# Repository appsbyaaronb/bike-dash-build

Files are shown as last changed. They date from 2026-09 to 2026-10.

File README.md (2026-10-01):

# bike-dash-build

Hardware + software build notes for the **permanent** electric-motorcycle dash.
This repo is the "how to build it" companion to two existing repos:

| Repo | What it holds |
|---|---|
| [appsbyaaronb/bike-dash](https://github.com/appsbyaaronb/bike-dash) (private) | The dash firmware (ESPHome/LVGL): GPS speed, BMS status, media strip, SD ride log |
| [appsbyaaronb/ant-bms-epaper-gauge](https://github.com/appsbyaaronb/ant-bms-epaper-gauge) (public) | The original e-paper SOC gauge; the ANT-BMS BLE logic came from here |

## The decision (2026-09-18)

Cost is not a factor. Performance and start-up time are.

| Question | Answer |
|---|---|
| Compute | **ESP32-P4 + ESP32-C6** under ESPHome. About 3 s from key-on to a usable screen. Everything already written for bike-dash carries over. |
| Why not a Pi / Linux board | 15-30 s boot. Rejected. |
| Why not STM32H7 | Under 1 s boot but no BLE and nothing carries over. Rejected. |
| Why not the Waveshare ESP32-P4-7B we started on | Its panel is **350 nits, 0-60 C**. Every ESP32-P4 all-in-one board on the market (Waveshare, Guition, Elecrow) is an indoor panel. A bike dash in direct sun needs about 1000 nits. |
| Screen | **Riverdi RVT70HSMNWC00-B**: 7" 1024x600 IPS, **850 cd/m2**, optically bonded PCAP touch, anti-glare, **-20 to 70 C**, glove and wet-screen touch. Controller EK79007 (same family as Espressif's own dev panel), runs 2-lane. |
| Board | **Waveshare ESP32-P4-NANO** (P4 + onboard C6, 32 MB PSRAM, 16 MB flash, microSD, 15-pin 1.0 mm 2-lane DSI). |
| Glue | Two FPC breakouts for the bench, an eletechsup LD24AJTA constant-current driver (pot-set) for the 9.6 V / 270 mA backlight, a Pololu 5 V buck off the bike's 12 V. A small carrier PCB replaces the breakouts for the on-bike install. |

## Bench wiring at a glance

Bench wiring diagram

Full pin-by-pin steps, checks and troubleshooting: [docs/wiring.md](docs/wiring.md).

## Where things are

| File | Contents |
|---|---|
| [docs/bom.md](docs/bom.md) | Every part, price, link, and order status |
| [docs/wiring.md](docs/wiring.md) | **Pin-for-pin wiring guide.** Start here when the parts arrive. |
| [docs/hardware.md](docs/hardware.md) | Pinouts, panel electrical limits, timings, gotchas (the reference behind the wiring guide) |
| [docs/software.md](docs/software.md) | ESPHome bring-up plan, versions, stages |
| [esphome/bike-dash-p4nano.yaml](esphome/bike-dash-p4nano.yaml) | Starting config: P4-NANO + Riverdi panel as a `mipi_dsi` CUSTOM model |
| [esphome/bike-dash-live.yaml](esphome/bike-dash-live.yaml) | **Current working firmware** (no panel yet): BMS over BLE, iPhone media remote, dash page on :8080, fixed IP |
| [esphome/components/](esphome/components/) | Custom components: `ams` (iPhone Apple Media Service remote), `dash_page` (serves dash pages, media/restart commands), `log_page` (device log with a fixed-size buffer) |
| [esphome/dash.html](esphome/dash.html) | 1024x600 dash page, built into the firmware (:8080) |
| [esphome/phone.html](esphome/phone.html) | Phone dash, 19.5:9, scales to the window (:8082) |
| [docs/build-log.md](docs/build-log.md) | Dated log of what was done and what was learned |
| [enclosure/](enclosure/README.md) | OpenSCAD model, STLs and previews of the printed housing (bezel, retainer, shell, GPS cap) |

## Enclosure at a glance

Enclosure mockup

Four printed parts, PETG/ASA, M3 inserts. Details, hardware list and the VERIFY table: [enclosure/README.md](enclosure/README.md).

## Status

- 2026-09-18: research done, all core parts ordered (Amazon plus the Riverdi panel from DigiKey). Nothing built yet.
- 2026-09-18: enclosure mockup modelled in OpenSCAD, STLs exported. Several dimensions still need calipers on the real parts (see enclosure/README.md).
- 2026-09-28: board flashed. BMS live over the C6, iPhone media control working, dash page at `http://192.168.7.18:8080/`. Panel and GPS not connected yet.
- 2026-10-01: the P4-NANO display socket turned out to be 15-pin 1.0 mm, not 22-pin; the right breakout and cable are ordered (due Oct 3). Whole plan re-checked against Riverdi's datasheet for the exact panel; corrections are in docs/build-log.md.
- Board pages: dash `:8080`, log `:8081`, phone dash `:8082`, ESPHome web/API `:80`. Fixed IP 192.168.7.18 on IoT2.4; the iPhone hotspot is the backup network.

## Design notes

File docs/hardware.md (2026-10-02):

# Hardware reference

This is the reference behind [wiring.md](wiring.md). Read wiring.md to build it; come here when something does not work.

## Riverdi RVT70HSMNWC00-B panel

Riverdi's files for this exact part, in the folder https://download.riverdi.com/RVT70HSMNWC00-B/ : datasheet `DS_RVT70HSMNWC00-B V1.1A_Rev.1.0.pdf` (2026-07-20), drawing `DR_RVT70HSMNWC00-B V1.1A_Rev.1.0.pdf`, backlight app note `AN_RVT70HSMNWC00-B_Rev1.1.pdf`. The old Rev 1.4 link is dead. Do not commit the PDFs, link them.

These documents are for module revision **V1.1A**. The panel bought from DigiKey is listed as **V1.0A**. The pinout matches the 2024 app note, which covers both, so the electrical side is safe; treat the mechanical numbers as approximate until measured. Everything below was re-checked against these files on 2026-10-01.

| Item | Value |
|---|---|
| Controller | EK79007AD3 + EK73217BCGA (datasheet drawing). Espressif ships `esp_lcd_ek79007`; ESPHome `mipi_dsi` drives it as `model: CUSTOM` |
| Resolution | 1024 x 600, IPS, normally black, anti-glare |
| Brightness | 1000 cd/m2 bare; 850 cd/m2 with the optically bonded touch |
| Operating temp | -20 to 70 C (storage -30 to 80) |
| Logic supply | VDD 3.3 V (3.0-3.6), 110 mA typ, 120 max. Touch adds about 98 mA on its own 3.3 V pin. The NANO's 3.3 V regulator is a 3 A buck, so this is fine. |
| Backlight | 27 white LEDs, 9 strings of 3. **Vf 9.0 V typ (8.4-10.2), If 270 mA**, about 2.4 W. Absolute maximum is 30 mA per string, which is 270 mA total: **270 mA is the ceiling, not a midpoint.** No driver on the panel. |
| Touch | ILITEK ILI2132A PCAP, I2C address **0x41** (or USB HID), 10-point, thick-glove and wet operation. Not supported by ESPHome yet. |
| Touch tail | Separate 10-pin FPC off the touch controller board (printed on the tail): 1 GND, 2 VDD5V, 3 D-, 4 D+, 5 GND, 6 VCC, 7 RST, 8 SCL, 9 INT, 10 SDA. Pins 2-4 are a USB HID path, pins 6-10 the I2C path. The controller board also has a small white JST socket (CN1, the same USB signals). Wired over I2C in this build: wiring.md Step 4a. I2C VDD is 3.3 V only. |
| Size | Cover glass 179.96 x 119.00 mm, 1.1 mm thick. TFT body 164.9 x 100 mm. Whole module 7.68 mm thick max. Active area 154.21 x 85.92 mm. |
| Tail | 40-pin 0.5 mm pitch FPC, 0.3 mm thick, contacts on one side |
| Touch tail | 10-pin 0.5 mm pitch FPC, 0.3 mm thick |

### 40-pin FPC pinout (datasheet)

| Pin | Name | Note |
|---|---|---|
| 1 | NC | |
| 2, 3 | VDD | 3.3 V |
| 4 | NC | |
| 5 | RESET | active low; datasheet Note 1 has a recommended RC reset circuit |
| 6 | STBYB | standby, high for normal operation. Driven from GPIO5 (P1 pin 11) |
| 7 | GND | |
| 8, 9 | D0N, D0P | MIPI lane 0 |
| 10 | GND | |
| 11, 12 | D1N, D1P | MIPI lane 1 |
| 13 | GND | |
| 14, 15 | D2N, D2P | lane 2, **leave unconnected** (P4 is 2-lane) |
| 16 | GND | |
| 17, 18 | DCLKN, DCLKP | MIPI clock |
| 19 | GND | |
| 20, 21 | D3N, D3P | lane 3, **leave unconnected** |
| 22 | GND | |
| 23, 24 | NC | |
| 25 | GND | |
| 26-29 | NC | |
| 30 | GND | |
| 31, 32 | LED- | backlight cathode |
| 33 | L/R | horizontal scan direction. **Must be tied**: 3.3 V = left to right (normal) |
| 34 | U/D | vertical scan direction. **Must be tied**: GND = top to bottom (normal) |
| 35-38 | NC | |
| 39, 40 | LED+ | backlight anode |

### Init sequence (datasheet section 13). This is what goes in the ESPHome `init_sequence`

```
0x01            ; DCS software reset
delay 120 ms
0xB2 0x50       ; lanes: 0x50 = 2-lane, 0x60 = 3, 0x70 = 4   <-- P4 uses 2
0x80 0x4B       ; gamma
0x81 0xFF
0x82 0x1A
0x83 0x88
0x84 0x8F
0x85 0x35
0x86 0xB0
0x11            ; exit sleep
delay 120 ms
0x29            ; display on
delay 20 ms
```

### Timing (datasheet, typical / range)

| Parameter | Typ | Range |
|---|---|---|
| Pixel clock | 51.2 MHz | 44.9-63 MHz |
| H active | 1024 | |
| H total (one line) | 1344 | 1200-1400 |
| HSYNC pulse | no typ given; config uses 10 | 1-140 |
| H back porch | 160 | fixed |
| H front porch | 160 | 16-216 |
| V active | 600 | |
| V total | 635 | 624-750 |
| VSYNC pulse | no typ given; config uses 1 | 1-20 |
| V back porch | 23 | fixed |
| V front porch | 12 | 1-127 |

### Gotchas from the datasheet

- **THS_ZERO**: the panel's MIPI receiver does not meet the MIPI minimum. If the host's THS_ZERO sits at the low end the panel may not initialise correctly and the picture "jumps". Riverdi says to set THS_ZERO to about **213 ns** in the DSI PHY. ESPHome has no setting for it; it would be an ESP-IDF PHY timing change.
- The pulse widths are 10 and 1, not 70 and 10: with a 70-wide pulse the line comes to 1414 clocks, over the 1400 maximum. 10/160/160 and 1/23/12 are what Espressif's `esp_lcd_ek79007` driver and the ESPHome Waveshare 7B preset use for the same controller (`lane_bit_rate: 900Mbps`, `pclk 52MHz`).
- That same Espressif driver sends `0xB2, 0x10` for 2 lanes and different gamma bytes. Riverdi's datasheet says `0x50`. The config uses Riverdi's; `0x10` is the first thing to try if the panel stays black.

## Waveshare ESP32-P4-NANO

Wiki: https://www.waveshare.com/wiki/ESP32-P4-Nano-StartPage . Schematic: https://files.waveshare.com/wiki/ESP32-P4-NANO/ESP32-P4-NANO-schematic.pdf

| Item | Value |
|---|---|
| SoC | ESP32-P4NRW32, 32 MB PSRAM in package, 16 MB QSPI flash |
| Radio | ESP32-C6-MINI-1 over SDIO: reset GPIO54, cmd 19, clk 18, d0-d3 = 14-17, active high (ESPHome device page) |
| I2C | SDA GPIO7, SCL GPIO8 (also on the DSI connector) |
| LCD reset (BSP default) | GPIO27 on the GPIO header |
| LCD backlight PWM (BSP default) | GPIO26 on the GPIO header |
| DSI | 15-pin 1.0 mm FPC (J1, "15PIN--PI4B", Raspberry Pi 4 layout), 2 lanes + clock. Pins: 1 GND, 2 D1-, 3 D1+, 4 GND, 5 CLK-, 6 CLK+, 7 GND, 8 D0-, 9 D0+, 10 GND, 11 SCL, 12 SDA, 13 GND, 14-15 3V3. We only use the six MIPI signals and ground from this connector; reset and backlight go from the header instead. |
| Power | USB-C, or 5 V on the header, or PoE module |

Header **P1** (2x13, 2.54 mm), from the schematic. Every pin this build uses is on P1:

| Pin | Signal | Use | | Pin | Signal | Use |
|---|---|---|---|---|---|---|
| 1 | 3V3 | panel 33 (L/R) | | 2 | 5V | Pololu 5 V in |
| 3 | GPIO7 | I2C SDA (touch) | | 4 | 5V | GPS 5V |
| 5 | GPIO8 | I2C SCL (touch) | | 6 | GND | |
| 7 | GPIO23 | touch RST | | 8 | GPIO37 | |
| 9 | GND | | | 10 | GPIO38 | |
| 11 | GPIO5 | panel STBYB (pin 6) | | 12 | GPIO4 | |
| 13 | GPIO20 | GPS UART TX (P4 → GPS RX) | | 14 | GND | |
| 15 | GPIO21 | GPS UART RX (GPS TX → P4) | | 16 | GPIO22 | touch INT |
| 17 | 3V3 | touch VCC | | 18 | GPIO24 | USB-Serial-JTAG D−, left free |
| 19 | GPIO25 | USB-Serial-JTAG D+, left free | | 20 | GND | |
| 21 | GPIO26 | backlight PWM | | 22 | GPIO27 | panel RESET |
| 23 | GPIO32 | | | 24 | GPIO33 | |
| 25 | GND | | | 26 | GPIO36 | |

Header P2 carries GPIO0-3, 6, 45-48, 53, 54 and the C6 UART; not used here.

Storage is microSD (SDIO 3.0). The only ESPHome preset for this board is `WAVESHARE-P4-NANO-10.1` (their 10.1" DSI panel); copy only the board-level bits.

## Backlight driver: eletechsup LD24AJTA

- Buck constant-current, 6-24 V in, 30-900 mA set by a pot. Ceiling is 0.1 V / RCS. Ordered 2026-09-28 from AliExpress ($1.15).
- Set to **260 mA** on a meter before connecting the panel, never above 270 (wiring.md step 1). Bare pads: VIN, GND, LED+, LED-, PWM, GND.
- Buck topology: Vin must be above the LED string (9.0 V typ, 10.2 max) plus headroom. 12 V is fine. 5 V is not. Headroom not in the listing; check brightness on the bench at 12 V.
- PWM pad: 100 Hz-20 kHz per the listing. The LEDC output on GPIO26 runs about 5 kHz.
- Riverdi's own reference design drives the backlight with a TPS61169 boost from 2.7-5.5 V and PWM at 5-100 kHz. That is for their chip, not a limit of the panel.
- Replaces the PT4115 modules: those arrived with a 1R0 sense resistor (100 mA, about 37 % brightness). Getting 270 mA from them needs a 0.36-0.39 ohm 1206 resistor swap (DigiKey RL1206FR-070R36L).

## Pololu D36V28F5

5.3-50 V in, 5 V 3.2 A out, reverse-polarity protected, has an EN pin (tie to ignition-switched 12 V if we want the dash off with the key without a relay).

## On-bike carrier PCB (later)

Replace both breakouts and the jumpers with one board: 15-pin 1.0 mm FPC in, 40-pin FPC out, DSI pairs as 100 ohm differential traces, PT4115 + Pololu footprints (or discrete equivalents), fuse, ignition-sense input. Design it only after the bench build shows the panel initialising.

## Antennas

None to buy for the bench. All radios have on-board antennas; the rules for the bike install:

| Radio | Rule |
|---|---|
| BLE, C6 on the P4-NANO (PCB antenna) | Plastic enclosure. Keep the NANO away from the panel's driver strip and the MIPI wires; the e-paper gauge showed display electronics desensing the radio. |
| GPS, SparkFun chip antenna | Must see sky: top of the enclosure, plastic lid, nothing metal above it. If first fix is slow or speed drops out, swap to the SparkFun NEO-M9N u.FL version plus a small active patch antenna (about $12) mounted outside. |
| XIAO C6 (contingency) | Same as BLE; it has a u.FL socket if an external antenna is ever needed. |
| Metal enclosure | Do not. Everything would need external antennas. |

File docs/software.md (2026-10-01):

# Software plan

The dash application lives in [bike-dash](https://github.com/appsbyaaronb/bike-dash). This repo only covers getting the new hardware to light up. Once the display works, the bike-dash YAML gets its `esp32`, `esp32_hosted`, `display` and `light` blocks swapped for the ones here.

## Versions

| Thing | Requirement |
|---|---|
| ESPHome | 2026.9 or newer. 2026.8 fixed the ESP32-P4 rev3 bootloop; 2026.9 dropped the old `esp_hosted` 2.0.11 path that double-freed on P4+C6 |
| Framework | esp-idf only (no Arduino on P4), IDF 5.3 or newer for `esp32_hosted` |
| Build host | Linux is easiest (the gaming PC on CachyOS). Windows works from PowerShell, **not** MSys/Git-Bash (idf_tools.py rejects it) |

## Bring-up stages

| Stage | Goal | Done when |
|---|---|---|
| 0 | P4-NANO boots ESPHome, C6 comes up | logs show Wi-Fi/BLE from `esp32_hosted`. **Do this with nothing but USB plugged in.** |
| 1 | Riverdi panel initialises | backlight on, screen not black, no DSI errors in the log. The test lambda fills the screen green with a grey box |
| 2 | LVGL hello at 1024x600 | a label renders, no tearing, PSRAM frame buffer |
| 3 | Merge bike-dash UI | the speed-hero layout from bike-dash renders here |
| 4 | BMS BLE over the C6 | `'soc': Sending state NN %` in the log (same GO/NO-GO as bike-dash Stage 1) |
| 5 | GPS, SD logging, phone media | iPhone only. Apple Media Service (AMS) over BLE: **play/pause, volume up/down** are the required controls; next/previous and track title come free with it. Custom ESPHome component (esp-idf). Fallback if AMS fights us: a BLE HID consumer-control device (media keys), which iOS also accepts natively but gives no track info. No Android support needed. |
| 6 | Touch | Wanted. Wired over I2C (wiring.md Step 4a); done-when for the wiring is a device at 0x41 in the I2C scan. ILI2132A is **not** an ESPHome touchscreen platform, so it needs a custom `ili2132` component (port of Linux `ilitek_ts_i2c`). Last, because the dash is useful without it |

## The display block

See [esphome/bike-dash-p4nano.yaml](../esphome/bike-dash-p4nano.yaml). Key points:

- `model: CUSTOM` with `dimensions`, timings and the datasheet `init_sequence` (see hardware.md).
- `lanes: 2` and the `0xB2 0x50` byte in the init sequence must agree.
- Start at `lane_bit_rate: 900Mbps` and `pclk_frequency: 51.2MHz`; if the picture is scrambled try 800-1000 Mbps.
- Sync pulses are 10 (H) and 1 (V). One line must stay within 1200-1400 clocks.
- If it stays black with a clean log: THS_ZERO (hardware.md), then RESET polarity and timing, then STBYB, then `0xB2, 0x10`.
- The config with the display block bootlooped on 2026-09-28 with no panel attached. Retest with the panel wired before assuming a config fault.

## Commands

```
esphome config esphome/bike-dash-p4nano.yaml                          # validate
esphome run    esphome/bike-dash-p4nano.yaml --device /dev/ttyACM1    # Linux (gaming PC: the board is ACM1)
esphome run    esphome/bike-dash-p4nano.yaml --device COM4            # Windows PowerShell
```

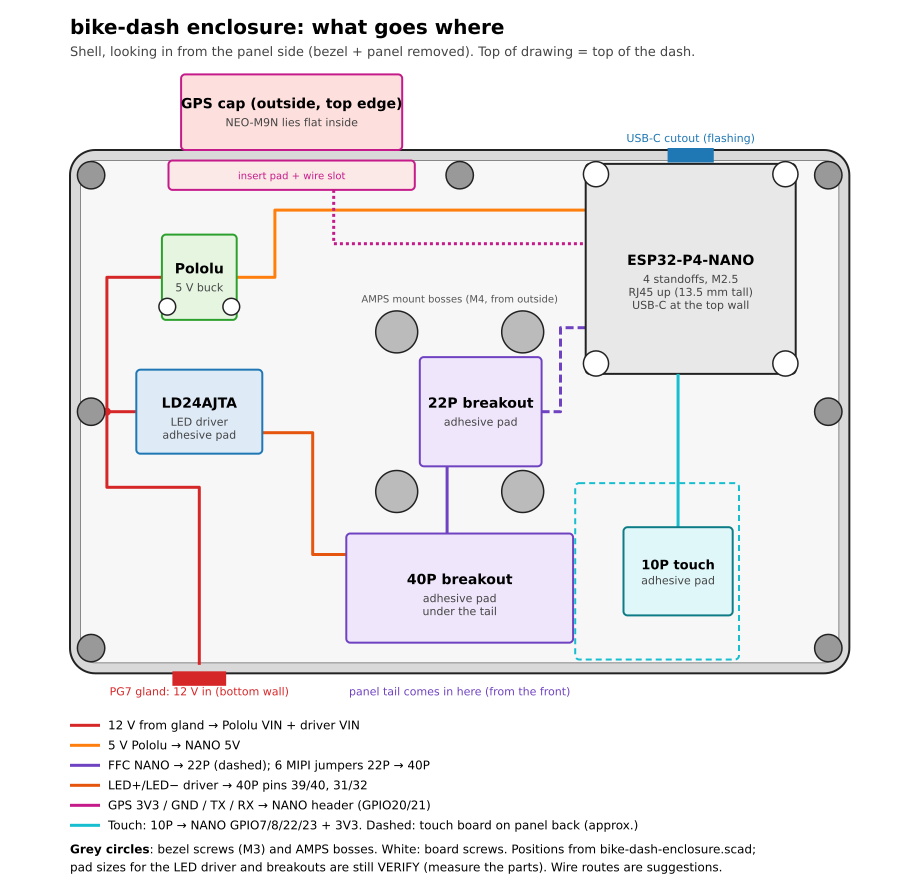
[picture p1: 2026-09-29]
enclosure/previews/layout.png

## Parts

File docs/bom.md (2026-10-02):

# Bill of materials

Ordered 2026-09-18 unless noted. Prices are what was on screen that day.

## Core

| # | Part | Vendor | Price | Link | Status |
|---|---|---|---|---|---|
| 1 | Riverdi RVT70HSMNWC00-B, 7" 1024x600 IPS 850 cd/m2 optical-bonded PCAP touch, MIPI-DSI, no frame | DigiKey (SM-RVT70HSMNWC00-B V1.0A) | $116.07 | [DigiKey](https://www.digikey.com/en/products/detail/riverdi/SM-RVT70HSMNWC00-B-V1-0A/25855280) / [Riverdi direct $113.52](https://riverdi.com/product/high-brightness-ips-display-rvt70hsmnwc00-b-7-inch-projected-capacitive-touch-panel-optical-bonding-uxtouch-mipi-dsi) | ordered 2026-09-18 |
| 2 | Waveshare ESP32-P4-NANO (bare board) | Amazon | $28.79 | [search, first result](https://www.amazon.com/s?k=Waveshare+ESP32-P4-NANO) | ordered 2026-09-18 |
| 3 | MECCANIXITY 40-pin 0.5 mm FPC breakout, 2-pack (panel side) | Amazon | $7.99 | [B09VPHW2QY](https://www.amazon.com/MECCANIXITY-Converter-Socket-2-54mm-Printer/dp/B09VPHW2QY) | ordered 2026-09-18 |
| 3b | MECCANIXITY 40-pin 0.5 mm FPC breakout, **2x20 female socket header already fitted** (no soldering; use this one on the panel side). Female header: jumpers into it need a male end | Amazon | $9.99 | MECCANIXITY store, "FFC FPC Connector Board 40 Pin 0.5mm 2.54mm to 1.0mm 2.54mm" | ordered 2026-10-02, due Oct 3 |
| 4 | ~~MECCANIXITY 22-pin 0.5 mm FPC breakout, 2-pack~~ **wrong part, not used**: the P4-NANO DSI socket is 15-pin 1.0 mm. Replaced by 4b | Amazon | $9.39 | [B09VPKWL1G](https://www.amazon.com/MECCANIXITY-Converter-2-54mm-Single-Printer/dp/B09VPKWL1G) | ordered 2026-09-18 |
| 4b | MECCANIXITY 15-pin **1.0 mm** FPC breakout, 2.54 mm double-row header (P4-NANO DSI side) | Amazon | $8.49 | MECCANIXITY store, "FFC FPC Connector Board 15 Pin 1mm" | ordered 2026-10-01, due Oct 3 |
| 4c | uxcell 15-pin 1.0 mm FFC cable, 100 mm, 10-pack (spare for the cable in the NANO box; contact side not stated) | Amazon | $5.99 | uxcell store | ordered 2026-10-01, due Oct 3 |
| 5 | PT4115 constant-current LED driver module, 3-pack (backlight) | Amazon | $7.99 | [B0FR1SGWKM](https://www.amazon.com/PT4115-Constant-Current-Dimming-Step-Down/dp/B0FR1SGWKM) | arrived 2026-09-28 with 1R0 (100 mA); replaced by 5b |
| 5b | eletechsup LD24AJTA adjustable CC LED driver, 30-900 mA, PWM (backlight, set to 260 mA) | AliExpress (eletechsup Outlet Store) | $1.15 | [4000340845096](https://www.aliexpress.com/item/4000340845096.html) | ordered 2026-09-28, due Oct 04-09 |
| 5c | ~~22-pin 0.5 mm FFC cable, 10 cm~~ **wrong part, not used** (see 4c) | Amazon | — | — | ordered 2026-09-28 |
| 5d | MECCANIXITY 10-pin 0.5 mm FPC breakout, 2-pack, shrouded 2x5 header fitted (touch tail) | Amazon | $7.99 | [B0CZ97XHVV](https://www.amazon.com/MECCANIXITY-Connector-Adapter-Converter-Digital/dp/B0CZ97XHVV) | ordered 2026-09-28, due Oct 3 |
| 5e | EDGELEC Dupont jumpers, 120 pcs assorted (F-F / M-M / M-F), 20 cm (power, control, GPS, touch) and 10 cm (the 6 MIPI wires) | Amazon | $6.98 each | EDGELEC store | ordered 2026-09-28 |
| 5f | ~~3V3 splitter~~ | — | — | — | **not needed** (2026-10-02: GPS on 5V pin 4, STBYB on GPIO pin 11) |
| 6 | Pololu D36V28F5 5 V 3.2 A buck, 5.3-50 V in (bike 12 V to 5 V) | Amazon | $16.99 | [B0BJKVWR2D](https://www.amazon.com/Pololu-3-2A-Step-Down-Voltage-Regulator/dp/B0BJKVWR2D) | ordered 2026-09-18 |
| 7 | **SparkFun GPS Breakout NEO-M9N, chip antenna (Qwiic)**: genuine u-blox M9, 25 Hz max, UART pins + I2C, **3.3 V supply and logic**, rechargeable backup battery keeps settings and gives a hot fix | Amazon | $74.95 | [B082YG1PXF](https://www.amazon.com/SparkFun-Breakout-Breadboardable-time-First-f/dp/B082YG1PXF) (Prime) | ordered 2026-09-18 |
| 8 | USB-to-TTL serial adapter, 3.3 V (for the one-time 10 Hz / 115200 setup in u-center) | Amazon | about $8 | any CP2102 or FT232 board with a 3.3 V switch | ordered 2026-09-18 |

All eight core parts ordered 2026-09-18 (Amazon plus the panel from DigiKey). The panel on that DigiKey listing is module revision V1.0A; Riverdi's current datasheet is for V1.1A (hardware.md).

GPS notes: it is the speed source for the dash (speed and trip come from GPS, not the bike). Many cheap "NEO-M8N" boards on Amazon are clones with old firmware, so the SparkFun board is the pick. Alternative if it is out of stock: [Matek M9N-5883](https://www.amazon.com/s?k=Matek+M9N-5883) ($62.99, genuine, but **5 V supply**, JST-GH pigtail, and no flash: it forgets its settings when its supercap drains, so the `on_boot` block in the YAML becomes mandatory). Whatever module: it must run at **10 Hz** and **115200 baud** (factory default is 1 Hz at 9600 or 38400, too slow for a speedo). See wiring.md Step 4b.

## Still to source (bench)

| Part | Why | Notes |
|---|---|---|
| Screw terminal or small perfboard | To join the 12 V feeds on the bike. (No 3.3 V joins needed any more: every 3.3 V wire has its own pin.) | |
| 12 V bench supply, 2 A | Backlight + buck | A 12 V wall adapter with a barrel jack pigtail is fine |
| Multimeter | Setting the LED driver to 260 mA (10A jack) and the 5 V rail before connecting the panel | |

## Still to source (on-bike)

| Part | Why |
|---|---|
| Carrier PCB (15-pin DSI in, 40-pin panel out, 10-pin touch in, LED driver, buck, connectors) | Replaces the two breakouts and jumper wires. Design after bench bring-up. |
| Enclosure + bezel for the 164.9 x 100 x 5.7 mm panel | Weatherproof, vibration |
| Automotive fuse (2 A) + inline connector on the 12 V feed | |

## Contingency (buy only if Stage 4 fails)

| Part | Why | Notes |
|---|---|---|
| Seeed XIAO ESP32-C6 (about $10, Amazon/Seeed) | Second BLE radio if the onboard C6 cannot hold the BMS link and the iPhone AMS link at once | Runs its own ESPHome firmware as the AMS peripheral; talks to the P4 over a spare UART (3V3, GND, TX, RX on two free header GPIOs). Onboard C6 keeps the BMS. Has a u.FL socket for an external antenna if the enclosure blocks BLE. |

## Alternatives that were rejected (so we do not re-research)

| Part | Why not |
|---|---|
| Waveshare ESP32-P4-WIFI6-Touch-LCD-7B ($47-56) | 350 nits. Fine as a bench unit, not the bike screen. Same ESPHome code otherwise. |
| Elecrow CrowPanel Advance 7" P4 (400 nits), Waveshare 7/8/10.1 HMI (400-450), Guition JC1060P470 | All indoor-brightness, 0-60 C panels |
| Riverdi STM32H7 7" 850-nit ($266) | No BLE, TouchGFX rewrite |
| Riverdi "ESP-P4 series" 10.1" 800-1000 nit all-in-one (coming soon) | Right idea, wrong size, no price or date. Watch it. |
| Amazon "1000 nit 7 inch" kits (VSDISPLAY etc.) | HDMI controller boards. The P4 has no HDMI out. |
| Adafruit 4905 40-pin breakout | Out of stock on Amazon; MECCANIXITY substituted |

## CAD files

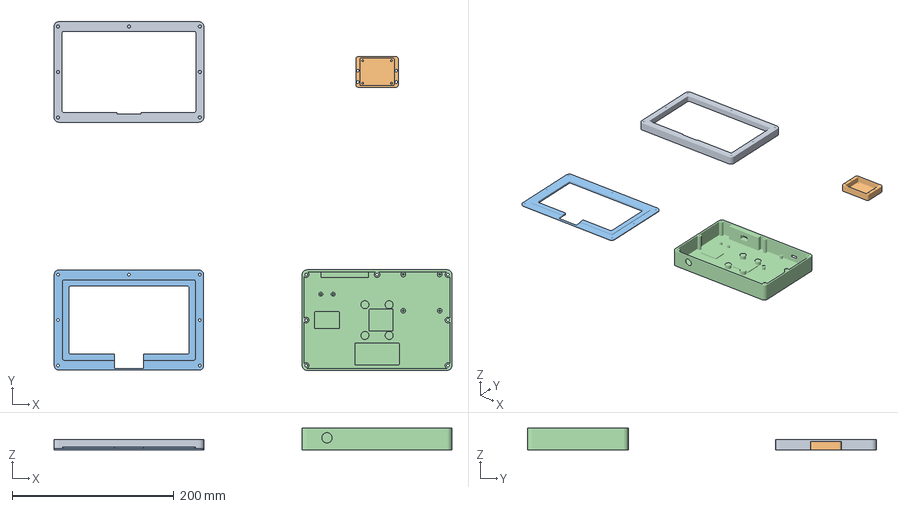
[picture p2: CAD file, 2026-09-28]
enclosure/bike-dash-enclosure.3mf
492.8 x 431.8 x 27.0 mm
bezel.stl
gpscap.stl
retainer.stl
shell.stl

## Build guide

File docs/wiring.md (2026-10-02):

# Wiring guide (bench build)

Written for someone who is not a wiring person. Every connection is listed pin by pin. Do the steps in order and do not skip the checks; the panel is the expensive part and the backlight is the one thing that can cook it.

## What you are building

Bench wiring diagram: every wire, colour-coded, with pin numbers at both ends

Same thing as text, for when the picture is too small on a phone:

```
                 +---------------------+          +--------------------------+
 12 V supply --->| Pololu D36V28F5     |--5 V---->| Waveshare ESP32-P4-NANO  |
    (bench:      | (12 V in, 5 V out)  |          |   15-pin DSI connector   |----15-pin FFC----> [15P breakout]
     wall wart;  +---------------------+          |   GPIO header            |                          |
     bike: fused                                  +--------------------------+                   13 short jumpers
     ignition 12 V)                                    |  GPIO27 (reset)  GPIO26 (dim)  3V3  GND        |
         |                                             |     |               |          |    |           v
         |       +---------------------+               |     |               |          |    |     [40P breakout] <--panel tail-- Riverdi 7" panel
         +------>| LD24AJTA LED driver |---LED+ / LED- ------------------------------------------------> pins 39/40 and 31/32
                 | (12 V in, 270 mA CC)|<-- DIM from GPIO26
                 +---------------------+
```

Three groups of wires:
1. **Power**: 12 V to the Pololu and the LED driver; 5 V from the Pololu to the P4-NANO; 3.3 V from the P4-NANO to the panel; one shared ground.
2. **Control**: panel RESET from GPIO27, LED driver PWM from GPIO26, panel STBYB from GPIO5 (header pin 11, driven high by the firmware).
3. **Video**: six MIPI wires (three pairs) from the P4-NANO's DSI connector to the panel. These are the only fussy ones.

## Tools

Multimeter, small flat screwdriver for the terminal blocks, wire strippers, a pack of female-female Dupont jumpers (100 mm), tweezers for the FPC latches, a 12 V 2 A supply.

## Step 0. Board alone, no panel (Stage 0 in software.md)

1. Plug the P4-NANO into the PC over USB-C. Nothing else connected.
2. Flash `esphome/bike-dash-nodisplay.yaml` (the same config without the `display:` block).
3. Confirm the log shows the C6 radio coming up and Wi-Fi connecting. If this does not work, nothing else matters yet. (Done 2026-09-28; the board now runs `bike-dash-live.yaml`.)

## Step 1. Set the LED driver current before it ever touches the panel

The backlight driver is an eletechsup LD24AJTA (AliExpress, "DC 6-24V 30-900mA Adjustable LED Driver"). Its current is set by a small pot, up to a ceiling of 0.1 V / RCS (the board's sense resistor). It can reach 900 mA, which will destroy the backlight, so it is set on a meter first. The pads are bare: solder six wires (VIN, GND, LED+, LED-, PWM, GND).

1. Meter: red probe in the **10A** jack, dial on 10A DC. The mA jack is often fused at 200 mA.
2. Turn the pot fully toward **decrease** (arrows are printed next to it).
3. 12 V to VIN / GND. Red probe on **LED+**, black on **LED-**, nothing else on the output. PWM open (floating = full on).
4. Power on. Turn the pot slowly toward increase until the meter reads **0.26 A**. Do not go past **0.27 A**: the panel datasheet gives 270 mA as the working current and its absolute maximum is 30 mA per LED string x 9 strings = 270 mA, so there is no headroom above it.
5. Power off, remove the meter. The setting holds whatever the load is.

If it stops rising around 0.10 A, RCS is too big (1 ohm = 100 mA ceiling); it needs 0.33 ohm or less.

The old PT4115 modules (Amazon 3-pack) came with a 1R0 sense resistor = 100 mA, about 37 % brightness. Usable for a dim bench test only.

## Step 2. Power wiring

All terminal blocks: strip 6 mm, insert, tighten, tug-test.

| From | To | Wire |
|---|---|---|
| 12 V supply + | Pololu **IN** | red |
| 12 V supply - | Pololu **GND** (either GND pad) | black |
| Pololu **OUT** (5 V) | P4-NANO header **5V**, pin 2 | red |
| Pololu **GND** (the other GND pad) | P4-NANO header **GND**, pin 6 | black |

The Pololu board prints **IN** and **OUT**. Its bottom row reads OUT, GND, GND, IN, EN; PG is the single hole above. Leave EN and PG open.

Check with the meter before going on: Pololu OUT to GND reads **4.9-5.1 V**. If it reads 12 V you wired IN and OUT backwards. Power off.

On the bench you can skip the Pololu and just use USB-C for the P4-NANO. You still need 12 V for the LED driver.

### LED driver, pad by pad

The driver board has two pads on one edge (**LED+**, **LED-**) and four on the other (**GND**, **VIN**, **GND**, **PWM**). The two GND pads are the same connection: one takes the supply, the other takes the P4-NANO ground. The old PT4115 (1R0) module has the same pads and wires the same way.

| Driver pad | Goes to | Wire |
|---|---|---|
| **VIN** | 12 V supply + | red |
| **GND** (next to VIN) | 12 V supply - | black |
| **GND** (next to PWM) | P4-NANO header **GND**, pin 9 (pin 6 has the supply) | black |
| **PWM** | P4-NANO header **GPIO26** (pin 21) | blue |
| **LED+** | panel pins 39 and 40 (Step 3) | red |
| **LED-** | panel pins 31 and 32 (Step 3). Never to ground. | black |

The driver needs 12 V: it cannot light the backlight from 5 V. If the P4-NANO runs from USB-C, the GND-to-GND wire above is what gives the PWM signal its return path, so do not skip it.

## Step 3. Panel side: the 40-pin breakout

1. Open the black latch on the 40-pin breakout's FPC socket (flip up or slide out, depending on the model).
2. Slide the panel's tail in **contacts facing the contacts in the socket**. The Riverdi tail has contacts on one side only; if the picture stays dead later, this is the first thing to flip.
3. Close the latch. Pin 1 of the tail is marked on the panel's drawing; the breakout has "1" printed at one end. Make sure they line up, or every pin below is off by one.

Now wire the breakout's header pins. Pin numbers are the **panel** pin numbers (they match the breakout's printed numbers when pin 1 lines up):

| Breakout pin | Panel signal | Goes to | Wire |
|---|---|---|---|
| 2 | VDD 3.3 V | 15-pin breakout pin **14** (3.3 V) | red |
| 3 | VDD 3.3 V | 15-pin breakout pin **15** (3.3 V) | red |
| 5 | RESET | P4-NANO header **GPIO27**, pin 22 | yellow |
| 6 | STBYB | header **pin 11** (the firmware drives it high) | yellow |
| 7 | GND | 15-pin breakout pin **10** | black |
| 10 | GND | 15-pin breakout pin **7** | black |
| 13 | GND | 15-pin breakout pin **1** | black |
| 16 | GND | 15-pin breakout pin **4** | black |
| 19 | GND | 15-pin breakout pin **13** | black |
| 22, 25, 30 | GND | **nothing** (same ground inside the panel as the five above) | |
| 33 | L/R (scan direction) | header **3V3**, pin 1 | red |
| 34 | U/D (scan direction) | P4-NANO header **GND**, pin 25 | black |
| 31 **and** 32 | LED- | LED driver **LED-** | black |
| 39 **and** 40 | LED+ | LED driver **LED+** | red |
| 8 | D0N | 15-pin breakout, DSI **D0-** (Step 4) | pair 1 |
| 9 | D0P | 15-pin breakout, DSI **D0+** | pair 1 |
| 11 | D1N | 15-pin breakout, DSI **D1-** | pair 2 |
| 12 | D1P | 15-pin breakout, DSI **D1+** | pair 2 |
| 17 | DCLKN | 15-pin breakout, DSI **CLK-** | pair 3 |
| 18 | DCLKP | 15-pin breakout, DSI **CLK+** | pair 3 |
| 1, 4, 23, 24, 26-29, 35-38 | NC | **nothing** | |
| 14, 15, 20, 21 | lanes 2-3 | **nothing** (the P4 is 2-lane) | |

Pins 33 and 34 are inputs with nothing on the panel holding them, so they must be wired. 33 to 3.3 V and 34 to GND is the normal picture (top to bottom, left to right), the same as Riverdi's own reference circuit. Swap either one to flip the picture that way.

Every ground and every 3.3 V wire has its own pin. Nothing is left as "any GND":

| Source pin | Feeds |
|---|---|
| Header **GND** pin 6 | Pololu GND |
| Header **GND** pin 9 | LED driver GND (the pad next to PWM) |
| Header **GND** pin 14 | GPS GND |
| Header **GND** pin 20 | touch tail pin 5 |
| Header **GND** pin 25 | panel pin 34 (U/D) |
| 15-pin breakout GND pins 10, 7, 1, 4, 13 | panel pins 7, 10, 13, 16, 19 |
| 15-pin breakout 3.3 V pins 14, 15 | panel pins 2, 3 (VDD) |
| Header **3V3** pin 17 | touch tail pin 6 (VCC) |
| Header **3V3** pin 1 | panel pin 33 (L/R) |
| Header **5V** pin 4 | GPS **5V** (the GPS has its own 3.3 V regulator) |

No splitter: every wire has its own pin. Panel pin 6 (STBYB) is a logic input, fed from header pin 11, which the firmware sets high at boot. (Panel pins 2 and 3 are not joined inside the panel, so both need their own wire.)

LED driver PWM: one wire from the driver **PWM** pad to P4-NANO header **GPIO26** (pin 21), plus the driver's second **GND** pad to a header **GND** pin (table in Step 2).

## Step 4. Video side: the 15-pin breakout on the P4-NANO

The P4-NANO's DSI socket (J1, marked "15PIN--PI4B" on the schematic) is a **15-pin 1.0 mm** FPC, the same as the display socket on a Raspberry Pi 4. The 15-pin FFC cable that ships in the NANO box goes from the NANO to a 15-pin 1.0 mm breakout; then thirteen jumpers go from the breakout to the 40-pin breakout: six video, five ground, two 3.3 V (table in Step 3).

The 22-pin 0.5 mm breakout and 22-pin FFC bought earlier do not fit this board. They are not used.

Pinout, read from the P4-NANO schematic (confirmed 2026-10-01):

| 15-pin pin | Signal | Goes to (40-pin breakout) | Wire |
|---|---|---|---|
| 1 | GND | pin **13** (GND) | black |
| 2 | DSI D1- | pin **11** (D1N) | pair 2 |
| 3 | DSI D1+ | pin **12** (D1P) | pair 2 |
| 4 | GND | pin **16** (GND) | black |
| 5 | DSI CLK- | pin **17** (DCLKN) | pair 3 |
| 6 | DSI CLK+ | pin **18** (DCLKP) | pair 3 |
| 7 | GND | pin **10** (GND) | black |
| 8 | DSI D0- | pin **8** (D0N) | pair 1 |
| 9 | DSI D0+ | pin **9** (D0P) | pair 1 |
| 10 | GND | pin **7** (GND) | black |
| 11 | I2C SCL (GPIO8) | **nothing** | |
| 12 | I2C SDA (GPIO7) | **nothing** | |
| 13 | GND | pin **19** (GND) | black |
| 14 | 3.3 V | pin **2** (VDD) | red |
| 15 | 3.3 V | pin **3** (VDD) | red |

Meter check before wiring (board powered **off**): the cable can leave the breakout's printed numbers running backwards. Put one probe on the P4-NANO header **3V3** pin and find the two breakout pins that beep. Those are pins 14 and 15. If they are the pins printed 1 and 2, the numbering is reversed: use 16 minus the printed number for every row above. Then confirm pins 1, 4, 7, 10 and 13 beep to a header **GND** pin.

If the cable will not seat or nothing beeps, the contacts are facing the wrong way at one end; flip that end over.

Rules for the six video jumpers:
- Same length, as short as you can (100 mm max on the bench).
- Keep each pair's two wires twisted together or taped side by side.
- Do not run them next to the 12 V wires.

Cables: use the 15-pin cable from the NANO box first. The uxcell 10-pack (100 mm, ordered 2026-10-01) is the spare; its contact side was not stated in the listing, so check it seats contacts-to-contacts at both ends.

## Step 4a. Touch (10-pin tail)

The touch tail is a separate 10-pin 0.5 mm FPC from the small board on the back of the panel. It goes into the 10-pin breakout. Pin numbers are the tail's (datasheet section 11.2).

| Tail pin | Signal | Goes to | Wire |
|---|---|---|---|
| 5 | I2C GND | P4-NANO header **GND**, pin 20 | black |
| 6 | I2C VDD | P4-NANO header **3V3**, pin 17. **Never 5 V on this pin.** | red |
| 7 | RST | P4-NANO header **GPIO23** (P1 pin 7) | yellow |
| 8 | SCL | P4-NANO header **GPIO8** (P1 pin 5) | white |
| 9 | INT | P4-NANO header **GPIO22** (P1 pin 16) | brown |
| 10 | SDA | P4-NANO header **GPIO7** (P1 pin 3) | green |
| 1, 2, 3, 4 | USB path (GND, 5 V, D-, D+) | **nothing** | |

The breakout has a 2x5 header. Which header pin is which tail pin has to be read off the board's printing (or beeped out) when it arrives.

Check: with it wired and the board running, the log's I2C scan should list a device at **0x41**. Nothing shows the touch points yet; the driver is not written (software.md Stage 6).

## Step 4b. GPS (speed source)

The P4-NANO has no dedicated GPS header; any two free header GPIOs become a UART. The config uses **GPIO20 = P4 TX (P1 pin 13), GPIO21 = P4 RX (P1 pin 15)** (change the `gps_tx_pin` / `gps_rx_pin` substitutions if those are taken on the silkscreen).

Four wires. TX goes to RX and RX goes to TX; that is the one everybody gets backwards.

| GPS pin (SparkFun NEO-M9N) | Goes to | Wire |
|---|---|---|
| **5V** (right-hand row, 2nd pin) | P4-NANO header **5V**, pin 4. The board's regulator makes 3.3 V from it. **Leave both GPS 3V3 pins empty: 5 V on a 3V3 pin kills it.** | orange |
| GND | P4-NANO header **GND**, pin 14 | black |
| TX (GPS talks) | P4-NANO header **GPIO21** (P1 pin 15, P4 RX) | green |
| RX (GPS listens) | P4-NANO header **GPIO20** (P1 pin 13, P4 TX) | white |

(If the Matek M9N-5883 was bought instead: its 5V pin goes to the header **5V**, and its RX/TX pins wire the same way. Its UART is 3.3 V logic too.)

No level shifting needed either way. Keep the antenna (the square ceramic patch) facing the sky with nothing metal on top of it; on the bike that means the top of the enclosure, not under the panel.

### One-time GPS setup (do this on the PC before wiring it to the P4)

Factory default is 1 update per second at 9600 baud, which makes a laggy speedo. We want 10 per second at 115200.

1. Connect the GPS to the USB-TTL adapter with the adapter's switch on **3.3 V**: 3V3-3V3, GND-GND, GPS TX to adapter RX, GPS RX to adapter TX. (If the SparkFun board's USB-C port shows up as a COM port on the PC, use that instead and skip the adapter.)
2. Install u-blox **u-center** (free, Windows). Connect at 9600 (Matek: 38400).
3. View > Messages View > UBX > CFG > RATE: set Measurement Period **100 ms**, click Send.
4. UBX > CFG > PRT: UART1, baud **115200**, Send. Reconnect u-center at 115200.
5. UBX > CFG > CFG: tick "Save current configuration", all devices (BBR + Flash if offered), Send.
6. Power-cycle the module and reconnect at 115200. If it is still at 10 Hz / 115200, done. If it forgot, the module has no flash or battery for settings: uncomment the `on_boot` block in the YAML, which re-sends the same settings every time the dash powers up.

The three UBX command strings the `on_boot` block sends (widely used values, verify against u-center's "Send" hex dump if in doubt):

| Purpose | Bytes |
|---|---|
| 10 Hz (CFG-RATE 100 ms) | `B5 62 06 08 06 00 64 00 01 00 01 00 7A 12` |
| 115200 baud (CFG-PRT UART1) | `B5 62 06 00 14 00 01 00 00 00 D0 08 00 00 00 C2 01 00 07 00 03 00 00 00 00 00 C0 7E` |
| Save (CFG-CFG) | `B5 62 06 09 0D 00 00 00 00 00 FF FF 00 00 00 00 00 00 17 31 BF` |

Test: with the dash running, the log prints satellites, speed and course from the `gps:` component. Outdoors it needs 30-90 s for a first fix; indoors near a window maybe, in a basement never.

## Step 5. Power-on order and first test

1. Meter check, power off: panel pin 2 to any GND must **not** be a short. Panel pin 39 to pin 31 must not be a short.
2. Power the 12 V supply. LED driver output is now live but nothing is drawn yet (it is fine; it is a current source, open circuit is safe).
3. Plug USB-C into the P4-NANO (or turn on the Pololu 5 V).
4. Flash the config **with** the `display:` block. Expect: backlight comes on (Stage 1), screen shows green with a grey box.

| Symptom | Check |
|---|---|
| Backlight off | GPIO26 jumper; DIM floating should mean full on, so if it is still off the LED driver has no 12 V or LED+/- are swapped |
| Backlight on, screen black, no errors in the log | Reset wire (GPIO27 to pin 5); STBYB wire (pin 11 to panel 6) and pin 11 reads 3.3 V after boot; panel tail inserted contacts-down vs contacts-up; THS_ZERO note in hardware.md; then try `0xB2, 0x10` in place of `0xB2, 0x50` in the init sequence (Espressif's value for this chip) |
| Picture jumps or will not hold still | THS_ZERO (hardware.md): the datasheet names exactly this symptom |
| Log shows DSI errors | A pair swapped, or a pair to the wrong lane; try swapping + and - of one pair, then lanes 0 and 1 |
| Scrambled or rolling picture | `lane_bit_rate` (try 800 or 1000 Mbps), then `pclk_frequency` |
| Picture mirrored or upside down | panel pin 33 (L/R) or 34 (U/D): move that wire between 3V3 and GND. Also the result of leaving them unconnected. |
| Panel gets hot | stop; check the LED driver current (Step 1) |
| I2C scan shows nothing at 0x41 | touch tail seated and the right way up; pin 6 has 3.3 V; SDA and SCL not swapped |

## Step 6. Bike install (later)

Same connections, but: the two breakouts and jumpers become a carrier PCB, the 12 V comes from a fused ignition-switched feed, the Pololu EN pin follows the ignition, and everything lives in the enclosure with the panel. Do not put jumper wires on a motorcycle.

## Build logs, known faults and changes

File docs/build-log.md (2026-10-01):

# Build log

## 2026-09-18 - research and ordering

- Re-checked whether the Waveshare ESP32-P4-7B was still the right base. Compute: yes. Panel: no, 350 nits.
- Surveyed every ESP32-P4 all-in-one board on sale (Waveshare 7B / 7-8-10.1 HMI / 3.4C / 4C, Guition JC1060P470, Elecrow CrowPanel Advance 7, M5Stack Tab5). All 350-450 nits, all 0-60 C. None sunlight-readable.
- Found Riverdi RVT70HSMNWC00-B: 850 nits optical-bonded touch, -20 to 70 C, EK79007 controller, 2-lane capable per its own init code. $113.52 direct, $116.07 DigiKey (10 in stock).
- Confirmed ESPHome `mipi_dsi` has `model: CUSTOM` with `init_sequence`, `lanes: 2`, and a `WAVESHARE-P4-NANO-10.1` preset exists for the board.
- Confirmed the Riverdi backlight needs an external constant-current driver (9.6 V / 270 mA). Chose PT4115 modules (12 V in) and a Pololu D36V28F5 for 5 V.
- Amazon cart built (P4-NANO, 40P + 22P breakouts, PT4115 x3, Pololu). $71.15. Panel to be ordered from DigiKey.
- Rejected: Pi/CM5 (boot time), STM32H7 (no BLE), Amazon "1000 nit" HDMI kits (no HDMI on P4).
- Open items: which of GPIO37/38 on the P4-NANO DSI connector is LCD reset; PT4115 sense resistor value on the modules that arrive; 22-pin FFC cable orientation.
- Caught later the same day: the GPS (speed source) had been left out of this repo. Added to the BOM (SparkFun NEO-M9N chip-antenna breakout, $74.95 Prime, 3.3 V, backup battery; Matek M9N-5883 as the fallback; plus a USB-TTL adapter for the one-time 10 Hz / 115200 setup), wiring.md Step 4b, and `uart:` + `gps:` blocks in the YAML on GPIO24/25. Not ordered yet.
- Local repo moved to `C:\Users\anon\Nextcloud\server\bike-dash-build` (Nextcloud-synced).
- All core parts (rows 1-8 in bom.md) ordered 2026-09-18. Bench extras (22-pin FFC cable, jumpers, 12 V supply) still to buy when the boxes arrive.
- Enclosure mockup (gaming PC, OpenSCAD 2021.01): four parts (bezel, retainer plate, shell, GPS cap) in `enclosure/`, STLs and previews exported. P4-NANO outline (50 x 50, holes 45.10 x 45.09) and SparkFun M9N board drawing (40.64 x 33.02, holes 35.56 x 27.94) fetched from the vendor drawings. The Riverdi -B touch datasheet 404s on every revision tried, so the glass outline is from the listing and tagged VERIFY. PT4115 and breakout boards are on adhesive pads until measured.

## 2026-09-28 - first flash, BMS live, iPhone remote

- Flashed the P4-NANO from the gaming PC (ESPHome 2026.9.0, venv at `~/.venvs/esphome`). It shows up as `/dev/ttyACM1` through the CH343.
- ESPHome 2026.9 needs an `esp_ldo` block (channel 3, 2.5 V) for `mipi_dsi`; added to `bike-dash-p4nano.yaml`.
- The full config bootloops (abort during setup) with the display section enabled and no panel attached. `bike-dash-nodisplay.yaml` is the same config without the display section, and it boots clean. Retest with the panel connected.
- The C6 only does 2.4 GHz, so it joins `IoT2.4`. Fixed IP 192.168.7.18 set on the device (`manual_ip`).
- BLE failed at first: "Co-processor not responding". The factory C6 firmware was too old. Built the esp_hosted 2.12.12 slave from the managed component source (`idf.py set-target esp32c6 build`), embedded it (`firmware/c6_hosted_2.12.12.bin`) and installed it with the `esp32_hosted` update entity. After that, `Co-processor firmware 2.12.12` and BLE comes up.
- BMS over the C6 works: `ANT-BLE22AAUB-8066` auto-discovered, SOC 100 %, 87.88 V, 59.97 Ah, 21 C.
- iPhone remote (`components/ams`): Apple Media Service client, control only like the old Rockford PMX-BTUR (no audio to the dash). Lessons: let the phone start pairing (both sides starting it gave a DHKey mismatch), look up the CCCDs instead of assuming handle+1, and subscribe to the Remote Command characteristic or iOS ignores the commands.
- Dash page (`components/dash_page`, `dash.html`) served from the board at `http://192.168.7.18:8080/`. It reads live data from `/events` on :80 and sends media buttons to `POST /cmd?c=N` on :8080. Sending them straight to :80 from the page did nothing. It has a Simulate data demo mode.
- Range is a placeholder (60 mi full charge x SOC). Speed shows 0 until the NEO-M9N is wired.
- Later the same day:
  - The log page moved to its own port, `:8081`. It uses a fixed 32 kB ring buffer in PSRAM, so it can't grow. It has Clear log and Clear Bluetooth buttons. Once the BMS connects, Bluetooth lines are purged and no longer logged (`quiet_ble_when`).
  - Phone dash on `:8082`, laid out for a 19.5:9 screen and scaled to the window. JS shrinks the content until no section overflows. Brave on iOS kept serving a cached old page, so reload if a change doesn't show.
  - `dash_page` takes a list of pages, and each page gets its own port and httpd control port. `LWIP_MAX_SOCKETS` is now 32: with 13, the three and then four HTTP servers plus the browsers' open data connections stopped every port answering.
  - Dash buttons: Restart board (tap twice) and Restart Bluetooth (BLE off 2 s, then on, and BMS discovery resets). The AMS component re-registers after a BLE restart. Before that fix it left a stale link (`ESP_ERR_INVALID_STATE`).
  - Status words are coloured red or green with no dots: `GPS:<sats>`, `BMS`, `REC` (green while the log runs), and `wifi` when there's no IP. The IP and ports are on two lines, top right of the speed panel.
  - Second Wi-Fi network: the iPhone hotspot `aaron` (DHCP, needs Maximize Compatibility). `IoT2.4` keeps priority and the fixed .18.
  - The BMS stopped advertising late in the day. Neither the board nor the PC could see it, even after a power cycle. Suspect range or another connection holding it. Not resolved.
- Backlight driver change: the PT4115 modules have a 1R0 sense resistor (100 mA, about 37 % brightness). Ordered an eletechsup LD24AJTA (AliExpress, $1.15, due Oct 04-09): current set by a pot to 270 mA on a meter first. Bare pads, six wires. Diagram, wiring.md, hardware.md and BOM updated.
- GPS UART moved from GPIO24/25 (USB-Serial-JTAG pins, ESPHome warned) to GPIO20 TX / GPIO21 RX, header P1 pins 13/15. Configs, diagram, wiring.md, hardware.md, layout updated.

## 2026-10-01 - wrong DSI connector caught, full check against the datasheets

- The P4-NANO DSI socket is **15-pin 1.0 mm** (schematic J1, "15PIN--PI4B"), not 22-pin 0.5 mm. The 22P breakout and 22-pin FFC are unusable. Ordered a MECCANIXITY 15-pin 1.0 mm breakout ($8.49) and a uxcell 15-pin 1.0 mm 100 mm FFC 10-pack ($5.99), both due Oct 3. Pinout read from the schematic and written into wiring.md Step 4.
- Riverdi now publishes the datasheet, drawing and backlight app note for the exact -B part (module revision V1.1A; ours is V1.0A). The old no-touch Rev 1.4 link is dead. Checking everything against them found:
  - Panel pins **33 (L/R) and 34 (U/D)** set the scan direction and must be tied (33 to 3.3 V, 34 to GND). The docs had them as "leave open" and put scan direction in pins 22-30. Pins 22, 25, 30 are GND; 23, 24, 26-29 NC.
  - Sync pulse widths 70/10 made one line 1414 clocks, over the 1400 limit. Now 10/1 (Espressif's values for the EK79007).
  - Backlight: 270 mA is the absolute maximum (30 mA x 9 strings), not a midpoint, and there is no 315 mA figure. Target is now 260 mA. Vf is 9.0 V typ.
  - Touch: I2C address 0x41 confirmed, I2C VDD is 3.3 V only. The diagram's "try 5 V if silent" note was wrong and is gone. wiring.md had no touch step; added Step 4a.
  - VDD is 3.0-3.6 V at 110 mA (not 2.6 V / 168 mA). THS_ZERO target is about 213 ns.
- Checked and correct: header P1 pin table against the schematic, C6 SDIO pins, the 40-pin MIPI/reset/STBYB/LED pins, init sequence bytes, the touch tail pinout, GPS wiring. All three YAML files validate. No secrets in tracked files.
- Enclosure: not touched, by decision; it gets redone once everything works and is measured. Findings saved for then: TFT body is off-centre in the glass (5.90 right / 9.16 left / 11.58 top / 7.42 bottom, seen from the front); module is 7.68 mm thick max so the model's 5.7 mm TFT depth is about 0.9 mm short; the main FPC is 29.5 mm wide, about 1 mm right of the glass centre; the touch FPC is a second 35 mm tail about 49 mm right of centre and has no slot in the bezel or retainer; the M3 x 35, M2.5 x 8, M2 x 6 and GPS M3 x 6 screws are all longer than their holes are deep.

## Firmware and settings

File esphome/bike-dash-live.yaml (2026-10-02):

# bike-dash on Waveshare ESP32-P4-NANO + Riverdi RVT70HSMNWC00-B (7" 1024x600, 850 nit)
# Stage 0/1 bring-up config. Validate with `esphome config` first.
# Pins follow docs/wiring.md: panel RESET on GPIO27, LED driver PWM on GPIO26 (P4-NANO BSP defaults).

substitutions:
  bms_name_prefix: "ANT-BLE"
  name: bike-dash
  lcd_reset_pin: GPIO27
  lcd_stbyb_pin: GPIO5    # panel 40P pin 6 (STBYB), header P1 pin 11. Driven high = panel on
  backlight_pwm_pin: GPIO26
  gps_tx_pin: GPIO20   # P4 TX -> GPS RX. header P1 pin 13 (24/25 are the USB-Serial-JTAG pins)
  gps_rx_pin: GPIO21   # P4 RX <- GPS TX. header P1 pin 15
  touch_int_pin: GPIO22    # touch tail pin 9, header P1 pin 16 (ILI2132A, driver not written yet)
  touch_reset_pin: GPIO23  # touch tail pin 7, header P1 pin 7

esphome:
  name: ${name}

esp32:
  variant: esp32p4
  flash_size: 16MB
  cpu_frequency: 360MHz
  framework:
    type: esp-idf
    sdkconfig_options:
      # Three HTTP servers (:80, :8080, :8081) + API + browser streams overran the default 13.
      CONFIG_LWIP_MAX_SOCKETS: "32"

psram:
  mode: hex
  speed: 200MHz

logger:
  hardware_uart: UART0
  level: DEBUG

# Onboard ESP32-C6 (Wi-Fi 6 / BLE) over SDIO. Values from the ESPHome device page for the P4-NANO.
esp32_hosted:
  variant: ESP32C6
  active_high: true
  reset_pin: GPIO54
  cmd_pin: GPIO19
  clk_pin: GPIO18
  d0_pin: GPIO14
  d1_pin: GPIO15
  d2_pin: GPIO16
  d3_pin: GPIO17

api:
ota:
  platform: esphome

wifi:
  # Two fixed IPs below, so ESPHome needs to be told which one OTA/logs use by default (home).
  use_address: 192.168.7.18
  networks:
    # Home IoT (2.4 GHz). Fixed IP so the dash pages are always at 192.168.7.18.
    - ssid: !secret wifi_ssid
      password: !secret wifi_password
      priority: 10
      manual_ip:
        static_ip: 192.168.7.18
        gateway: 192.168.7.1
        subnet: 255.255.255.0
        dns1: 192.168.8.105
        dns2: 9.9.9.9
    # iPhone hotspot (turn on Maximize Compatibility for 2.4 GHz). Fixed IP so the dash
    # pages are always at 172.20.10.9 (iPhone hotspots are always 172.20.10.0/28, phone = .1).
    - ssid: !secret wifi2_ssid
      password: !secret wifi2_password
      priority: 5
      manual_ip:
        static_ip: 172.20.10.9
        gateway: 172.20.10.1
        subnet: 255.255.255.240
        dns1: 172.20.10.1

i2c:
  sda: GPIO7
  scl: GPIO8
  frequency: 400kHz
  scan: true   # touch ILI2132A should show at 0x41

# GPS: u-blox M8/M10 on a UART. Module must be set to 10 Hz / 115200 (docs/wiring.md Step 4b).
uart:
  - id: gps_uart
    tx_pin: ${gps_tx_pin}
    rx_pin: ${gps_rx_pin}
    baud_rate: 115200
    rx_buffer_size: 2048

gps:
  uart_id: gps_uart
  latitude:
    name: GPS Latitude
  longitude:
    name: GPS Longitude
  altitude:
    name: GPS Altitude
  satellites:
    name: GPS Satellites
  course:
    name: GPS Course
  speed:
    name: GPS Speed
    id: gps_speed_kmh
    # ESPHome reports km/h; the dash wants mph
    on_value:
      then:
        - sensor.template.publish:
            id: speed_mph
            state: !lambda 'return x * 0.621371;'

sensor:
  - platform: ant_bms_ble
    ant_bms_ble_id: bms0
    soc:
      name: "soc"
      id: pack_soc
    total_voltage:
      name: "voltage"
      id: pack_voltage
    current:
      name: "current"
      id: pack_current
    capacity_remaining:
      name: "ah_remaining"
      id: pack_ah
    temperature_1:
      name: "temp1"
      id: t1
    temperature_2:
      name: "temp2"
      id: t2
    temperature_3:
      name: "temp3"
      id: t3
    temperature_4:
      name: "temp4"
      id: t4
  - platform: template
    id: speed_mph
    name: Speed
    unit_of_measurement: mph
    accuracy_decimals: 0

time:
  - platform: gps
    id: gps_time

# If the GPS module forgets its 10 Hz / 115200 setting on power loss (no flash / no battery),
# move this on_boot block under the existing `esphome:` key at the top so the dash re-sends it
# at every boot. The module boots at 9600 in that case, so the first two writes go out at 9600,
# then the UART is switched to 115200.
#   on_boot:
#     priority: -100
#     then:
#       - lambda: |-
#           id(gps_uart).set_baud_rate(9600); id(gps_uart).load_settings();
#       - uart.write: {id: gps_uart, data: [0xB5,0x62,0x06,0x08,0x06,0x00,0x64,0x00,0x01,0x00,0x01,0x00,0x7A,0x12]}
#       - uart.write: {id: gps_uart, data: [0xB5,0x62,0x06,0x00,0x14,0x00,0x01,0x00,0x00,0x00,0xD0,0x08,0x00,0x00,0x00,0xC2,0x01,0x00,0x07,0x00,0x03,0x00,0x00,0x00,0x00,0x00,0xC0,0x7E]}
#       - delay: 200ms
#       - lambda: |-
#           id(gps_uart).set_baud_rate(115200); id(gps_uart).load_settings();

# Panel STBYB (standby) is driven from a GPIO instead of a 3V3 splitter. High = panel running.
switch:
  - platform: gpio
    id: lcd_stbyb
    pin: ${lcd_stbyb_pin}
    restore_mode: ALWAYS_ON
    internal: true
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

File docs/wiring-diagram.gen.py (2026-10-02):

# Generates docs/wiring-diagram.svg: every wire ends on a numbered pin.
import sys
o=[]
A=o.append
RED='#d62728'; ORG='#ff7f0e'; PINK='#d63384'; BLK='#222'; GOLD='#b8860b'; BLUE='#1f77b4'
LEDP='#e6550d'; LEDM='#444'; M0='#6f42c1'; M1='#9467bd'; MC='#5b3a8e'; GRN='#2ca02c'; CYA='#17becf'
TEAL='#0e7c86'; BRN='#8c564b'
def box(x,y,w,h,fill='#f4f4f4',rx=6): A(f'<rect x="{x}" y="{y}" width="{w}" height="{h}" rx="{rx}" fill="{fill}" stroke="#222" stroke-width="1.5"/>')
def t(x,y,s,size=12,anchor='start',fill=None,bold=False,extra=''):
    a='' if anchor=='start' else f' text-anchor="{anchor}"'
    f=f' fill="{fill}"' if fill else ''
    b=' font-weight="bold"' if bold else ''
    A(f'<text x="{x}" y="{y}" font-size="{size}"{a}{f}{b}{extra}>{s}</text>')
def w(pts,color,dash=False,width=2.5):
    d=' stroke-dasharray="8 4"' if dash else ''
    A(f'<polyline points="{" ".join(f"{x},{y}" for x,y in pts)}" fill="none" stroke="{color}" stroke-width="{width}"{d}/>')
def dot(x,y,c): A(f'<circle cx="{x}" cy="{y}" r="4" fill="{c}"/>')

W,H=1500,1040
A(f'<svg xmlns="http://www.w3.org/2000/svg" viewBox="0 0 {W} {H}" width="{W}" height="{H}" role="img" aria-label="Bench wiring, every wire pin to pin. 12 V supply feeds the Pololu (IN, GND) and the LED driver (VIN, GND). Pololu OUT to NANO pin 2, GND to pin 6. LED driver PWM to pin 21, GND to pin 9, LED+ to panel 39/40, LED- to panel 31/32. NANO pin 22 to panel 5 RESET. NANO pin 1 (3V3) to panel 33. NANO pin 11 to panel 6 STBYB (driven high by the code). NANO pin 4 (5V) to GPS 5V. 15-pin breakout pins 14, 15 (3V3) to panel 2, 3; its GND pins 10, 7, 1, 4, 13 to panel 7, 10, 13, 16, 19; MIPI D0, D1, CLK pairs to panel 8/9, 11/12, 17/18. NANO pin 25 GND to panel 34. GPS: GND pin 14, TX to pin 15, RX to pin 13. Touch: SDA pin 3, SCL pin 5, INT pin 16, RST pin 7, VCC pin 17, GND pin 20.">')
A(f'<rect x="0" y="0" width="{W}" height="{H}" fill="#ffffff"/>')
A('<g font-family="Arial, Helvetica, sans-serif" font-size="12" fill="#222">')
t(750,28,'bike-dash bench wiring: every wire, pin to pin',18,'middle',bold=True)

# ---------- wires first (boxes drawn after would hide nothing: wires stop at box edges) ----------
# 12 V bus (x=30) and supply ground bus (x=50)
w([(110,120),(30,120),(30,565),(110,565)],RED)
A(f'<path d="M30,330 H44 A6,6 0 0 1 56,330 H110" fill="none" stroke="{RED}" stroke-width="2.5"/>')
dot(30,330,RED)
w([(110,150),(50,150),(50,535),(110,535)],BLK)
w([(50,305),(110,305)],BLK); dot(50,305,BLK)
t(22,230,'12 V +',11,'middle',RED,extra=' transform="rotate(-90 22 230)"')
t(64,230,'supply −',11,'middle',extra=' transform="rotate(-90 64 230)"')
# LED driver -> NANO (wrap under the driver)
w([(110,355),(75,355),(75,445),(470,445)],BLK)
w([(110,380),(92,380),(92,420),(470,420)],BLUE)
t(290,414,'PWM dim',11,'middle',BLUE)
t(290,459,'driver GND',11,'middle')
# Pololu -> NANO
w([(270,535),(470,535)],ORG); t(370,529,'5 V',11,'middle','#c8600a')
w([(270,565),(470,565)],BLK); t(370,579,'GND',11,'middle')
# LED+ / LED- over the top to the 40P breakout
w([(270,340),(320,340),(320,52),(1235,52),(1235,110)],LEDP)
w([(270,370),(338,370),(338,64),(1165,64),(1165,110)],LEDM,dash=True)
t(640,44,'LED+  (backlight, about 9 V / 260 mA)',11,'middle',LEDP)
t(640,78,'LED−  (backlight return to the driver, NOT to ground)',11,'middle',LEDM)
# GPS
w([(770,150),(900,150),(900,145)],BLK)
w([(770,172),(950,172),(950,145)],GRN)
w([(770,194),(1000,194),(1000,145)],CYA)
# pin 4 (5V) -> GPS 5V, pin 11 -> panel 6 STBYB, pin 1 (3V3) -> panel 33
w([(770,225),(1050,225),(1050,145)],ORG)
w([(770,250),(1130,250)],GOLD); t(1010,244,'STBYB',11,'middle','#8a6508')
w([(770,275),(1130,275)],PINK)
# RESET
w([(770,305),(1130,305)],GOLD); t(1010,299,'RESET',11,'middle','#8a6508')
# FFC band
A('<line x1="770" y1="480" x2="900" y2="480" stroke="#9a9a9a" stroke-width="14"/>')
t(835,466,'15-pin FFC cable',11,'middle')
# 15P -> 40P straight rows
rows15=[('14  3V3',PINK,'2  VDD 3.3 V'),('15  3V3',PINK,'3  VDD 3.3 V'),('10  GND',BLK,'7  GND'),
        ('8  D0−',M0,'8  D0N'),('9  D0+',M0,'9  D0P'),('7  GND',BLK,'10  GND'),
        ('2  D1−',M1,'11  D1N'),('3  D1+',M1,'12  D1P'),('1  GND',BLK,'13  GND'),
        ('4  GND',BLK,'16  GND'),('5  CLK−',MC,'17  DCLKN'),('6  CLK+',MC,'18  DCLKP'),('13  GND',BLK,'19  GND')]
ry=[385+24*i for i in range(13)]
for (a,c,b),y in zip(rows15,ry): w([(1030,y),(1130,y)],c)
# NANO pin 25 GND -> panel 34
w([(770,590),(885,590),(885,735),(1130,735)],BLK)
# touch
tr=[('pin 3',CYA,'10  SDA'),('pin 5',TEAL,'8  SCL'),('pin 16',BRN,'9  INT'),
    ('pin 7',GOLD,'7  RST'),('pin 17 (3V3)',PINK,'6  VCC (3.3 V)'),('pin 20 (GND)',BLK,'5  GND')]
ty=[615+25*i for i in range(6)]; tx=[870-15*i for i in range(6)]; by=[850+24*i for i in range(6)]
for (a,c,b),y,x,yy in zip(tr,ty,tx,by): w([(770,y),(x,y),(x,yy),(900,yy)],c)
# tails
A('<line x1="1300" y1="450" x2="1340" y2="450" stroke="#9a9a9a" stroke-width="14"/>')
t(1320,436,'tail',10,'middle')
A('<polyline points="1410,790 1410,910 1090,910" fill="none" stroke="#999" stroke-width="10"/>')
t(1250,898,'touch tail (10-pin, separate)',11,'middle','#555')
t(1250,932,'ILI2132A, I2C addr 0x41',10,'middle','#555')
t(1250,946,'VCC is 3.3 V only. Never 5 V.',10,'middle','#b00')
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

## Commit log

2026-09-28 Enclosure: slicer project (.3mf) with all four printed parts
    Claude-Session: https://claude.ai/code/session_01QXsZWkG9XYdnp423qbbPd9
    [bike-dash-enclosure.3mf]
2026-09-28 Update enclosure 3mf with A1 printer, process and PLA settings
    Replaces generic Default Printer/Filament settings (2 mm3/s flow cap,
    500 accel, generic G28/G29 start gcode) with Bambu Lab A1 0.4 nozzle,
    0.20mm Standard @BBL A1 and Generic PLA @BBL A1 profiles.
    Claude-Session: https://claude.ai/code/session_01TyEPGgYQYRcFrXP2HiGwE7
    [bike-dash-enclosure.3mf]
2026-09-28 Firmware: first flash, BMS over C6, iPhone media remote, dash page on :8080
    - bike-dash-live.yaml: working config (fixed IP, BMS BLE, AMS remote, web API, C6 fw update)
    - components/ams: Apple Media Service client (play/pause, next/prev, volume, track info)
    - components/dash_page: serves dash.html on :8080 plus POST /cmd for media buttons
    - firmware/c6_hosted_2.12.12.bin: C6 co-processor firmware matching esp_hosted 2.12.12
    - bike-dash-p4nano.yaml: add esp_ldo required by mipi_dsi on ESPHome 2026.9
    - Docs: build log for 2026-09-28, README file table, fix old repo links
    Claude-Session: https://claude.ai/code/session_01QXsZWkG9XYdnp423qb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
    [bike-dash-live.yaml, bike-dash-nodisplay.yaml]
2026-09-28 Dash page: BMS link dot (red/green) replaces the outside temp slot
    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
2026-09-28 Log page on :8081 (fixed 32 kB ring buffer), IP/ports or red wifi on the dash
    - components/log_page: serves the device log at :8081 from a PSRAM ring buffer that
    overwrites the oldest lines, so it can't grow; page polls only new bytes
    - Dash top bar (right of speed panel): IP + dash/log ports when on wifi, red wifi otherwise
    - LWIP_MAX_SOCKETS 13 -> 24 and LRU purge on the extra servers; three HTTP servers plus
    browser event streams had run the board out of sockets
    - Drop the BLE 'seen' debug logging
    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
    [bike-dash-live.yaml]
2026-09-28 Dash/log polish: restart button, log clear buttons, BT purge once BMS connects
    - Dash: GPS:<sats>, plain BMS/REC/wifi words coloured red or green, REC green while the
    device log runs, fixed-width play/pause, IP and ports on two lines, Restart board button
    (tap twice) under Ah remaining via POST /restart on :8080
    - Log page: Clear log and Clear Bluetooth buttons; Bluetooth chatter is purged and no
    longer logged once the BMS is connected (quiet_ble_when)
    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
    [bike-dash-live.yaml]
2026-09-28 Dash: Restart Bluetooth button; AMS recovers after Bluetooth restarts
    - POST /restart_bt on :8080: BLE off, 2 s, on; resets BMS discovery (on_bt_restart)
    - ams: when BLE goes inactive, drop the stale GATTC app and link state so it
    re-registers, re-advertises and the phone reconnects (was ESP_ERR_INVALID_STATE)
    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
    [bike-dash-live.yaml]
2026-09-28 Phone dash on :8082 (19.5:9, scales to window); second wifi (iPhone hotspot)
    - phone.html: same live data and controls, laid out on a 90x195 unit grid that scales to
    the window; portrait stacks, landscape splits speed / pack column
    - dash_page now takes a list of pages, each with its own port and httpd control port
    - wifi: networks list, IoT2.4 keeps the fixed .18, hotspot (wifi2_* secrets) uses DHCP
    - LWIP_MAX_SOCKETS 24 -> 32 for the fourth HTTP server; port list on dashes includes :8082
    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
    [bike-dash-live.yaml]
2026-09-29 Phone dash: auto-fit content to the frame so nothing is cut off
    Content sizes use --s = --u x fit; fit steps down until nothing overflows, rechecked on
    resize/rotation and every 5 s. Landscape speed digits smaller.
    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
2026-09-29 Docs: build log and README for log page, phone dash, restart buttons, second wifi
    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
2026-09-29 Backlight driver: eletechsup LD24AJTA (pot-set 270 mA) replaces PT4115 1R0 modules
    Claude-Session: https://claude.ai/code/session_01PP9Bb7M9mfMc4zGhLSab5Q
    [bike-dash-live.yaml, bike-dash-nodisplay.yaml, bike-dash-p4nano.yaml]
2026-09-29 Enclosure: labelled layout drawing (what goes where)
    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
2026-09-29 BOM: FFC cable, 10P touch breakout, jumper kits ordered
    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
2026-09-29 Wiring diagram + enclosure layout: touch (10P breakout, I2C GPIO7/8, INT 22, RST 23)
    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
2026-09-29 NANO header P1 pinout from the schematic; GPIO7/8/22/23/24/25/26/27 confirmed
    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
2026-09-29 Configs: touch INT/RST pin substitutions (GPIO22/23), I2C scan on
    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
2026-09-29 GPS UART to GPIO20/21 (P1-13/15), off the USB-Serial-JTAG pins
    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
2026-10-01 Live config: fixed IP 172.20.10.9 on the iPhone hotspot, use_address for home OTA
    Claude-Session: https://claude.ai/code/session_014646sJAMihm96m2SFyQo9j
    [bike-dash-live.yaml]
2026-10-01 DSI connector is 15-pin 1.0 mm; full check against Riverdi -B datasheet and NANO schematic
    - P4-NANO DSI socket is 15-pin 1.0 mm (J1), not 22-pin; pinout from the schematic,
    15P breakout and FFC ordered
    - Panel pins 33 (L/R) and 34 (U/D) must be tied; 22/25/30 are GND
    - Sync pulses 70/10 -> 10/1 (line was 1414 clocks, limit 1400)
    - Backlight target 260 mA, 270 mA is the absolute maximum
    - Touch: 3.3 V only, address 0x41, wiring Step 4a added
    - Datasheet links, panel electrical figures, repo link, serial port corrected
    - Enclosure findings parked in the build log; model not changed
    Claude-Session: https://claude.ai/code/session_014646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
    [bike-dash-p4nano.yaml]
2026-10-02 Wiring diagram: header P1 pin numbers on every NANO connection, plus a P1 pin map
    Claude-Session: https://claude.ai/code/session_01UKgkvzGngobRrYjcQeCgM5
2026-10-02 LED driver: show the pads as laid out on the board (GND, VIN, GND, PWM / LED+, LED-), pad-by-pad table
    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
2026-10-02 LED driver second GND goes to NANO header pin 9
    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
2026-10-02 LED driver PWM pad labelled with its NANO pin (21)
    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
2026-10-02 Diagram: draw the LED driver GND wire to a GND (pin 9) label on the NANO
    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
2026-10-02 Wiring: every ground and 3.3 V wire goes to a numbered pin; BOM adds 40P breakout with header fitted
    Diagram redrawn (docs/wiring-diagram.gen.py generates it): no floating ground
    symbols. Panel VDD and five panel grounds come from the 15-pin breakout, the
    rest from header GND pins 6/9/14/20/25. Header 3V3 pin 1 feeds a 1-to-3
    splitter for STBYB, L/R and GPS. Pololu pads named IN/OUT as printed.
    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
2026-10-02 Diagram: header pin number first on every NANO label, printed name in brackets
    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
2026-10-02 Diagram: NANO header shown by pin number only, GPIO names removed
    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
2026-10-02 Drop 3V3 splitter: GPS on 5V pin 4, panel STBYB on GPIO5 (pin 11)
    Panel pins 2/3 and 2/6 measured not joined inside the panel. STBYB is a
    logic input, so a GPIO driven high replaces the 3V3 feed; mipi_dsi
    enable_pin raises it before init. GPS uses its onboard regulator via 5V.
    Claude-Session: https://claude.ai/code/session_01RQNbUuKktVAUrgpcCH6v6f
    [bike-dash-live.yaml, bike-dash-nodisplay.yaml, bike-dash-p4nano.yaml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]
2026-10-12 Backlight: cap LED driver PWM at 28 % in firmware (0.262 A measured)
    The LD24AJTA is a PT4115 with a 0.11 ohm sense resistor and its pot has
    no effect, so it runs at 0.91 A whenever PWM is high or open. max_power
    0.28 at 1 kHz limits the average to the panel's 260 mA. Docs: check
    procedure, boot order, 1k PWM-to-GND pull-down for single-supply use.
    Claude-Session: https://claude.ai/code/session_01J6Le5YNtswpH6RP3rEPHay
2026-10-12 Diagram: 1k pull-down resistor between LED driver PWM and GND
    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
2026-10-12 BOM: 1k resistor for the LED driver PWM pull-down; LD24AJTA arrived
    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
